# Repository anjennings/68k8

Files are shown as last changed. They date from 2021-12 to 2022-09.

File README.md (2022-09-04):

# 68k8

## Specs
+ 68008 CPU
+ 68681 UART
+ 32K EEPROM
+ 2 x 512k SRAM Sockets 
	+ 2nd chip (lower) optional
+ Serial EEPROM 
	+ Remotely Programable
	+ Sizes Vary but 64k-128k Recommended
+ Micro SD Card
	+ I haven't even begun to test this so idk

## TODO List 1/7/21 (preferably in this order)
+ Arduino code for programming SROM
+ Wait for new 68681 chips to arrive
+ Finish UART A drivers
+ Finish Timer drivers
+ Test/Finish SROM Drivers
+ Order higher capacity SROM
+ Order sd card slot
+ Order 32-DIP socket for 2nd RAM slot
+ Write bootloader that boots from SROM
+ Solder SD card
+ Solder 2nd RAM socket
+ Assign traps to UART/SPI functions
+ Fuzix Branch

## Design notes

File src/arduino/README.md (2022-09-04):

# Arduino
Arduino projects used for testing and troubleshooting hardware issues

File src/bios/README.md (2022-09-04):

# 68k8 BIOS

Boots from 32k EEPROM, inits UART, and loads from Serial EEPROM if present

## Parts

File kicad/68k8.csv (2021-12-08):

Reference | Value | Footprint | Datasheet
U2 | L7805 | Package_TO_SOT_THT:TO-220-3_Vertical | http://www.st.com/content/ccc/resource/technical/document/datasheet/41/4f/b3/b0/12/d4/47/88/CD00000444.pdf/files/CD00000444.pdf/jcr:content/translations/en.CD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
U1 | LF33_TO220 | Package_TO_SOT_THT:TO-220-3_Horizontal_TabDown | http://www.st.com/content/ccc/resource/technical/document/datasheet/c4/0e/7e/2a/be/bc/4c/bd/CD00000546.pdf/files/CD00000546.pdf/jcr:content/translations/en.CD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
C1 | .1uF | Capacitor_THT:CP_Radial_D8.0mm_P2.50mm | ~
C2 | .33uF | Capacitor_THT:CP_Radial_D8.0mm_P2.50mm | ~
C3 | 2.2uF | Capacitor_THT:CP_Radial_D8.0mm_P2.50mm | ~
C4 | .1uF | Capacitor_THT:CP_Radial_D8.0mm_P2.50mm | ~
H0 | MountingHole | MountingHole:MountingHole_4mm | ~
H1 | MountingHole | MountingHole:MountingHole_4mm | ~
H2 | MountingHole | MountingHole:MountingHole_4mm | ~
H3 | MountingHole | MountingHole:MountingHole_4mm | ~
J00 | Barrel_Jack_Switch | Connector_BarrelJack:BarrelJack_Horizontal | ~
D0 | POW_LED | LED_THT:LED_D3.0mm | ~
R0 | 2K | Resistor_THT:R_Axial_DIN0309_L9.0mm_D3.2mm_P2.54mm_Vertical | ~
D1 | 1N4001 | Diode_THT:D_DO-41_SOD81_P10.16mm_Horizontal | ~
U400 | GAL16V8 | Package_DIP:DIP-20_W7.62mm_LongPads
C400 | 22pF | Capacitor_THT:C_Rect_L4.0mm_W2.5mm_P2.50mm | ~
U300 | 68681 | Package_DIP:DIP-40_W15.24mm_LongPads
U301 | MCP2221AxP | Package_DIP:DIP-14_W7.62mm_LongPads | http://ww1.microchip.com/downloads/en/DeviceDoc/20005565B.pdf
Y300 | 3.6864 MHz | Crystal:Crystal_HC18-U_Vertical | ~
22pF2 | CX2 | Capacitor_THT:C_Rect_L4.0mm_W2.5mm_P2.50mm | ~
22pF1 | CX1 | Capacitor_THT:C_Rect_L4.0mm_W2.5mm_P2.50mm | ~
J300 | Conn_01x02_Male | Connector_PinSocket_2.54mm:PinSocket_1x02_P2.54mm_Vertical | ~
C7 | 22pF | Capacitor_THT:C_Rect_L4.0mm_W2.5mm_P2.50mm | ~
J302 | USB_B | Connector_USB:USB_B_OST_USB-B1HSxx_Horizontal | ~
J301 | Conn_01x03_Male | Connector_PinSocket_2.54mm:PinSocket_1x03_P2.54mm_Vertical | ~
RN300 | 10K | Resistor_THT:R_Array_SIP5 | http://www.vishay.com/docs/31509/csc.pdf
J303 | Conn_01x07 | Connector_PinHeader_2.54mm:PinHeader_1x07_P2.54mm_Vertical | ~
C300 | 22pF | Capacitor_THT:C_Rect_L4.0mm_W2.5mm_P2.50mm | ~
C301 | 22pF | Capacitor_THT:C_Rect_L4.0mm_W2.5mm_P2.50mm | ~
RN301 | 2K | Resistor_THT:R_Array_SIP5 | http://www.vishay.com/docs/31509/csc.pdf
D300 | LED | LED_THT:LED_D3.0mm | ~
D301 | LED | LED_THT:LED_D3.0mm | ~
U330 | 25LCxxx | Package_DIP:DIP-8_W7.62mm | http://ww1.microchip.com/downloads/en/DeviceDoc/21832H.pdf
J330 | Conn_02x04_Top_Bottom | Connector_PinHeader_2.54mm:PinHeader_2x04_P2.54mm_Vertical | ~
U331 | 74LS126 | Package_DIP:DIP-14_W7.62mm | http://www.ti.com/lit/gpn/sn74LS126
C331 | 22pF | Capacitor_THT:C_Rect_L4.0mm_W2.5mm_P2.50mm | ~
C330 | 22pF | Capacitor_THT:C_Rect_L4.0mm_W2.5mm_P2.50mm | ~
U101 | 74LS07 | Package_DIP:DIP-14_W7.62mm | www.ti.com/lit/ds/symlink/sn74ls07.pdf
J320 | Micro_SD_Card_Det | Connector_Card:microSD_HC_Molex_104031-0811 | https://www.hirose.com/product/en/download_file/key_name/DM3/category/Catalog/doc_file_id/49662/?item_id=195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
RN320 | 10k | Resistor_THT:R_Array_SIP6 | http://www.vishay.com/docs/31509/csc.pdf
U100 | 68008D | Package_DIP:DIP-48_W15.24mm_LongPads | https://www.nxp.com/docs/en/reference-manual/MC68000UM.pdf
RN1 | R_Network10 | Resistor_THT:R_Array_SIP11 | http://www.vishay.com/docs/31509/csc.pdf
U102 | GAL16V8 | Package_DIP:DIP-20_W7.62mm_LongPads
CLK1 | 10.000 MHz | Oscillator:Oscillator_DIP-14 | http://cdn-reichelt.de/documents/datenblatt/B400/OSZI.pdf
C100 | 22pF | Capacitor_THT:C_Rect_L4.0mm_W2.5mm_P2.50mm | ~
C101 | 22pF | Capacitor_THT:C_Rect_L4.0mm_W2.5mm_P2.50mm | ~
C102 | 22pF | Capacitor_THT:C_Rect_L4.0mm_W2.5mm_P2.50mm | ~
C103 | 22pF | Capacitor_THT:C_Rect_L4.0mm_W2.5mm_P2.50mm | ~
U110 | LM555 | Package_DIP:DIP-8_W7.62mm_LongPads | http://www.ti.com/lit/ds/symlink/lm555.pdf
SW110 | SW_Push | Button_Switch_THT:SW_PUSH_6mm_H8.5mm | ~
C111 | 10nF | Capacitor_THT:C_Rect_L4.0mm_W2.5mm_P2.50mm | ~
 | 10uF | Capacitor_THT:C_Rect_L4.0mm_W2.5mm_P2.50mm | ~
C110 | 22pF | Capacitor_THT:C_Rect_L4.0mm_W2.5mm_P2.50mm | ~
C113 | 100nF | Capacitor_THT:C_Rect_L4.0mm_W2.5mm_P2.50mm | ~
U200 | AS6C4008-55PCN | Package_DIP:DIP-32_W15.24mm_LongPads | https://www.alliancememory.com/wp-content/uploads/pdf/AS6C4008.pdf
U202 | 28C256 | Package_DIP:DIP-28_W15.24mm_LongPads | http://ww1.microchip.com/downloads/en/DeviceDoc/doc0006.pdf
C200 | 22pF | Capacitor_THT:C_Rect_L4.0mm_W2.5mm_P2.50mm | ~
C201 | 22pF | Capacitor_THT:C_Rect_L4.0mm_W2.5mm_P2.50mm | ~
C202 | 22pF | Capacitor_THT:C_Rect_L4.0mm_W2.5mm_P2.50mm | ~
U201 | AS6C4008-55PCN | Package_DIP:DIP-32_W15.24mm_LongPads | https://www.alliancememory.com/wp-content/uploads/pdf/AS6C4008.pdf

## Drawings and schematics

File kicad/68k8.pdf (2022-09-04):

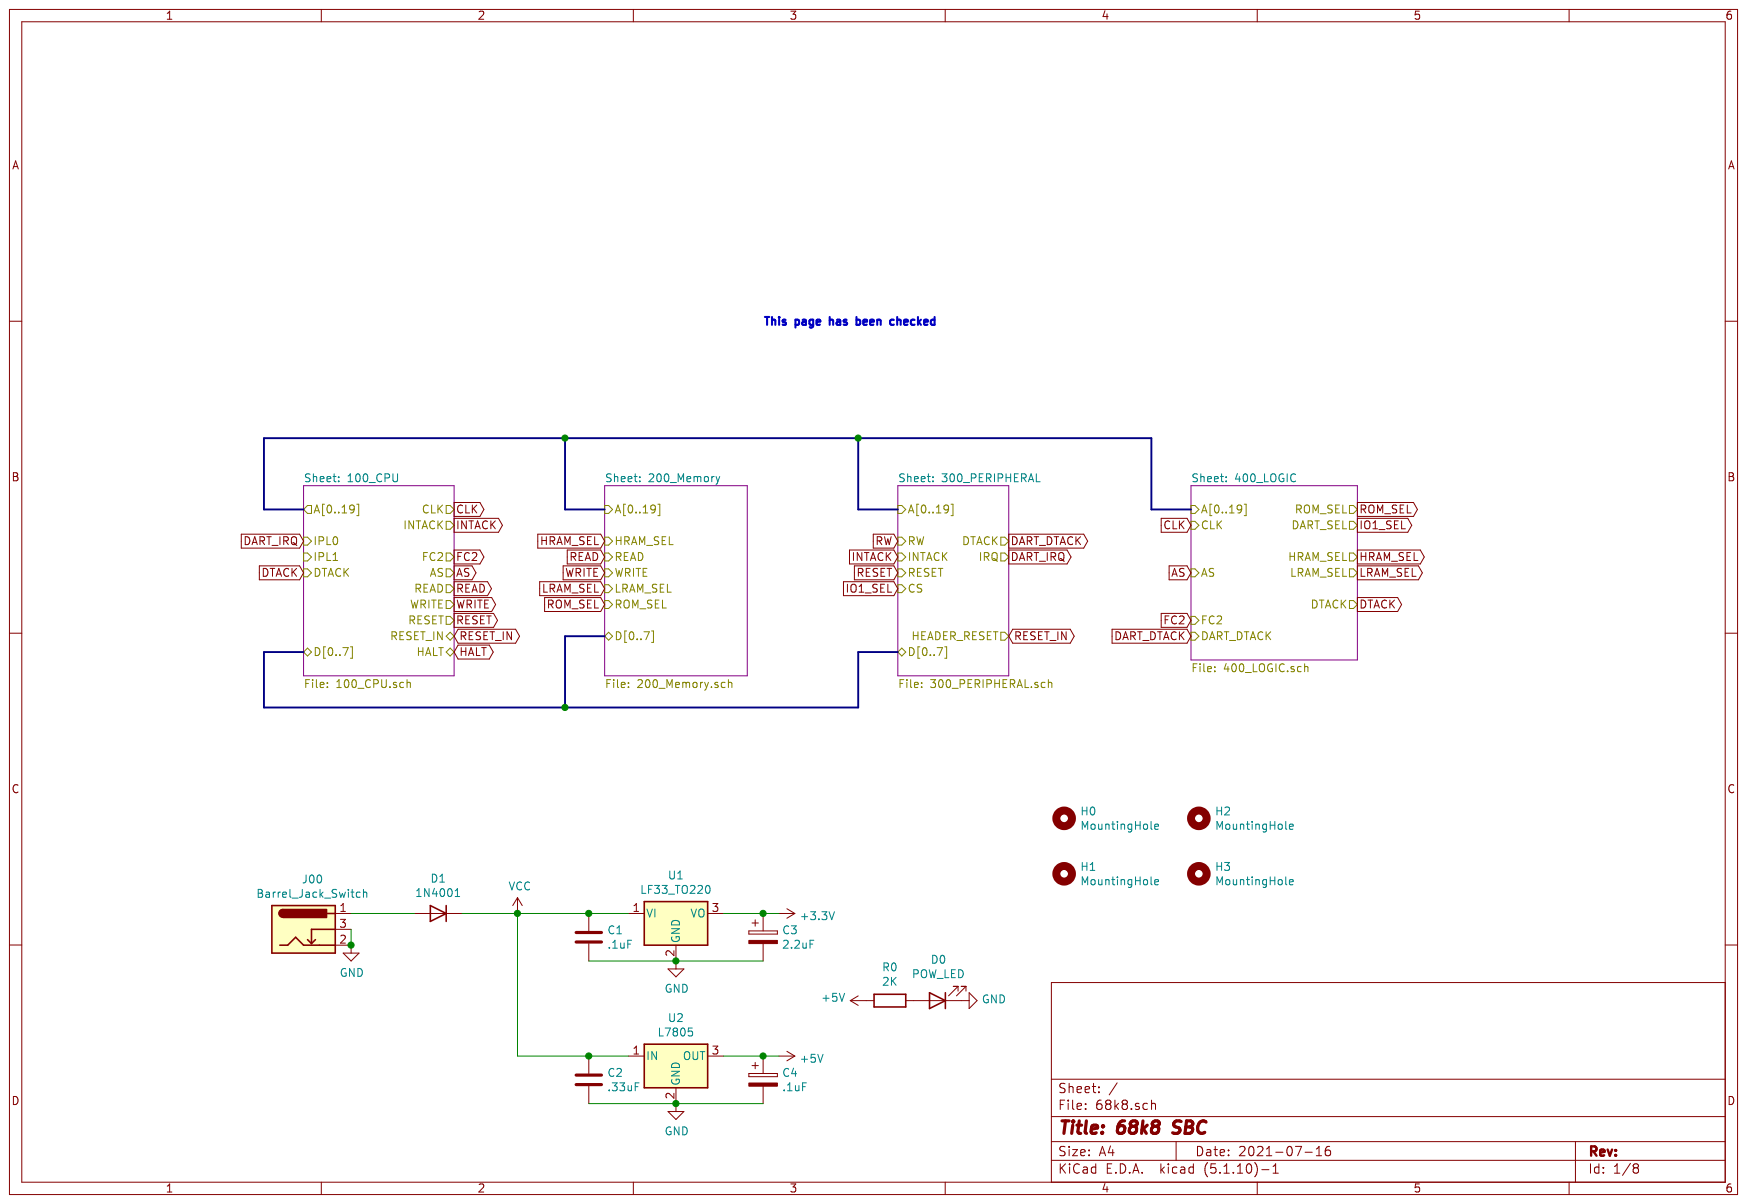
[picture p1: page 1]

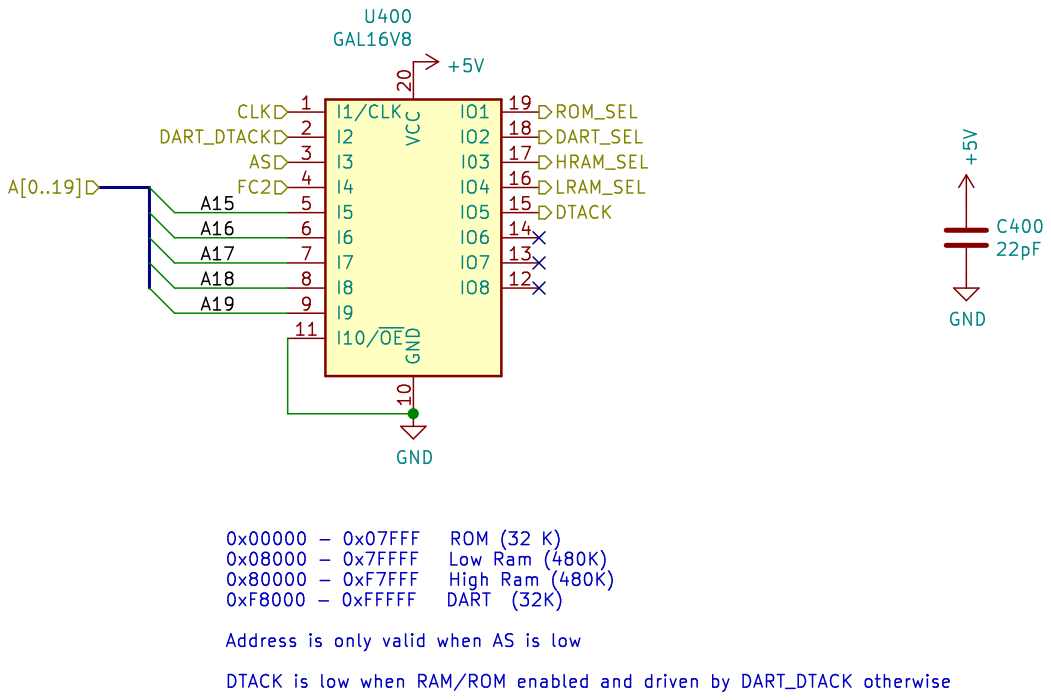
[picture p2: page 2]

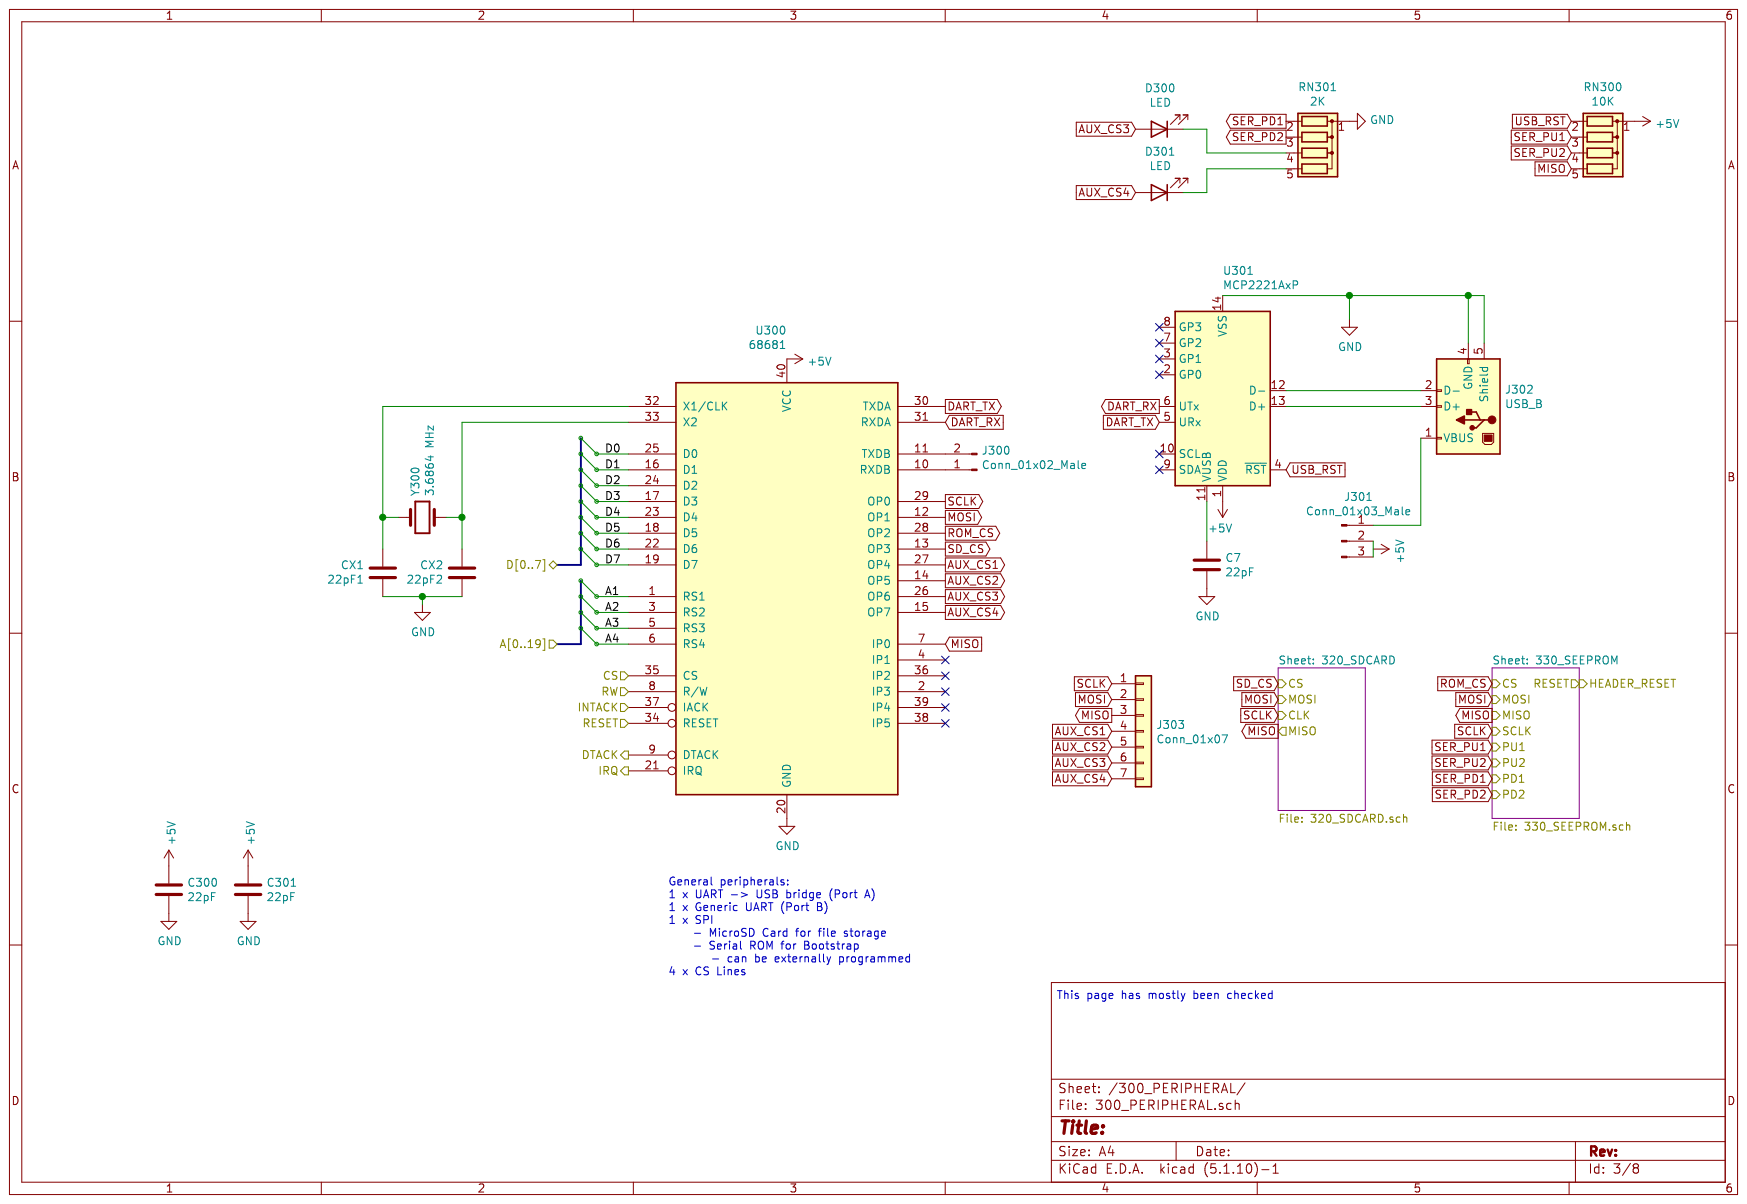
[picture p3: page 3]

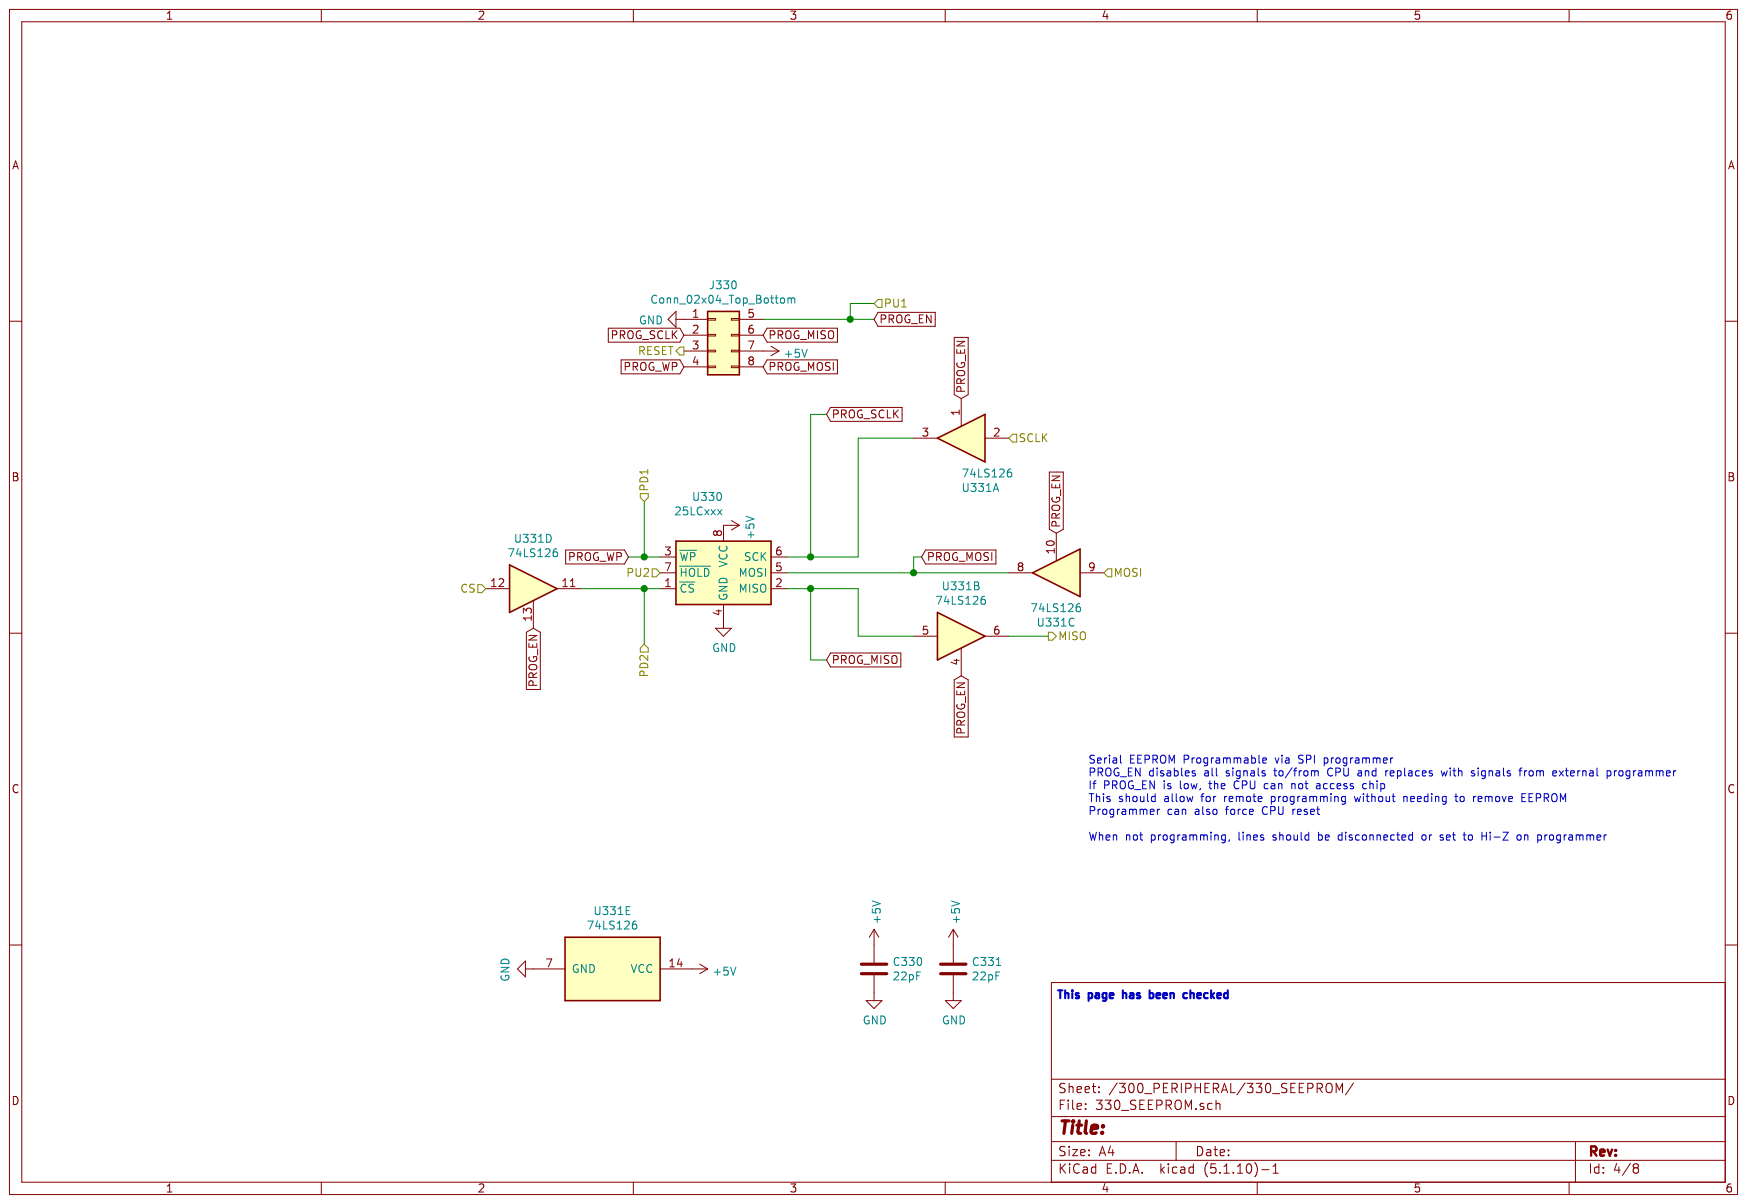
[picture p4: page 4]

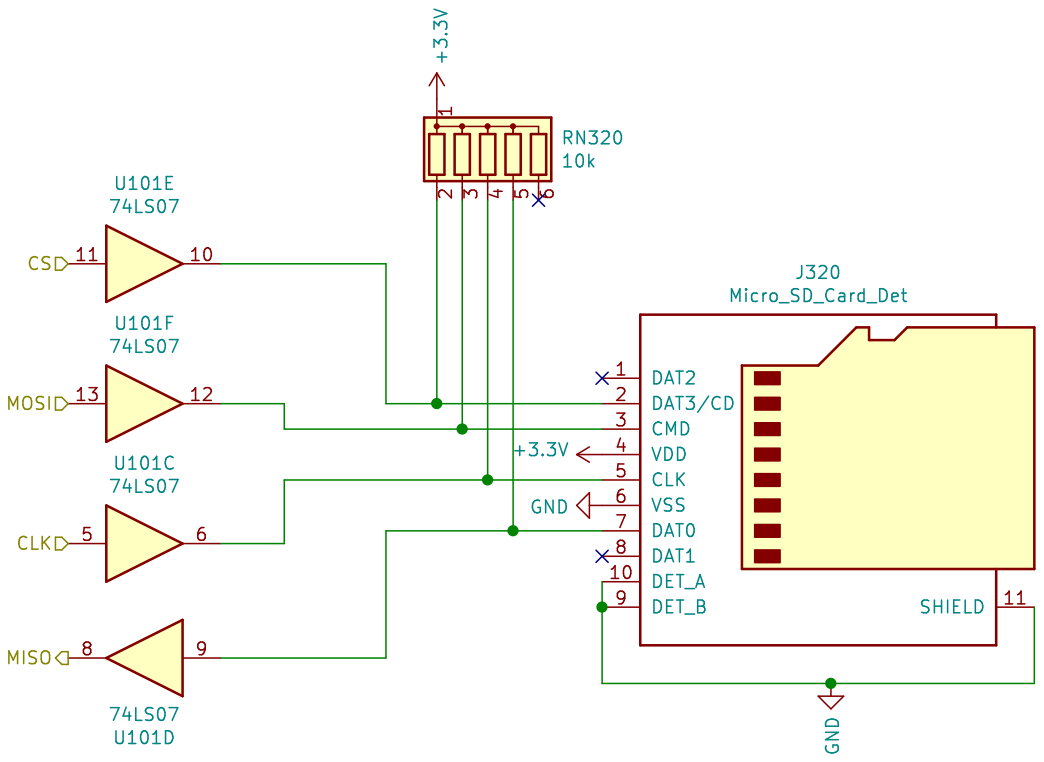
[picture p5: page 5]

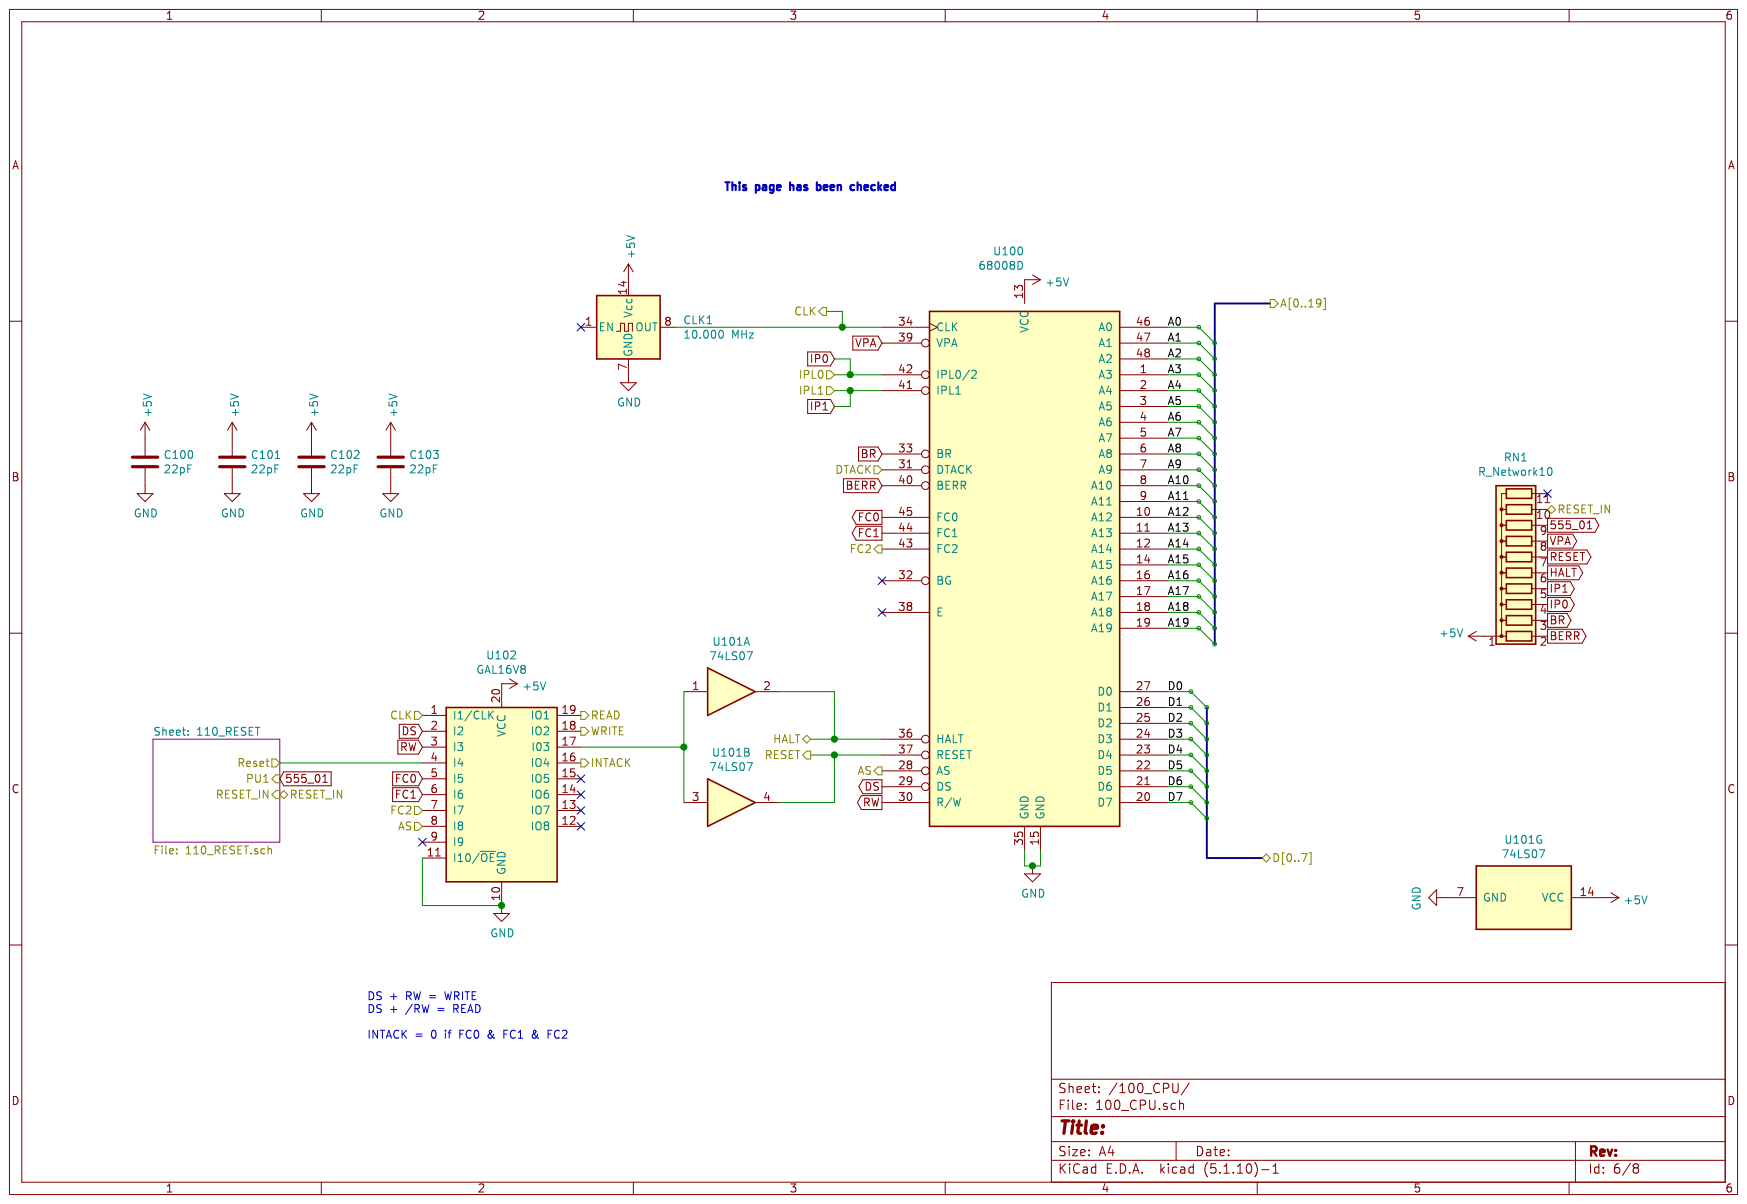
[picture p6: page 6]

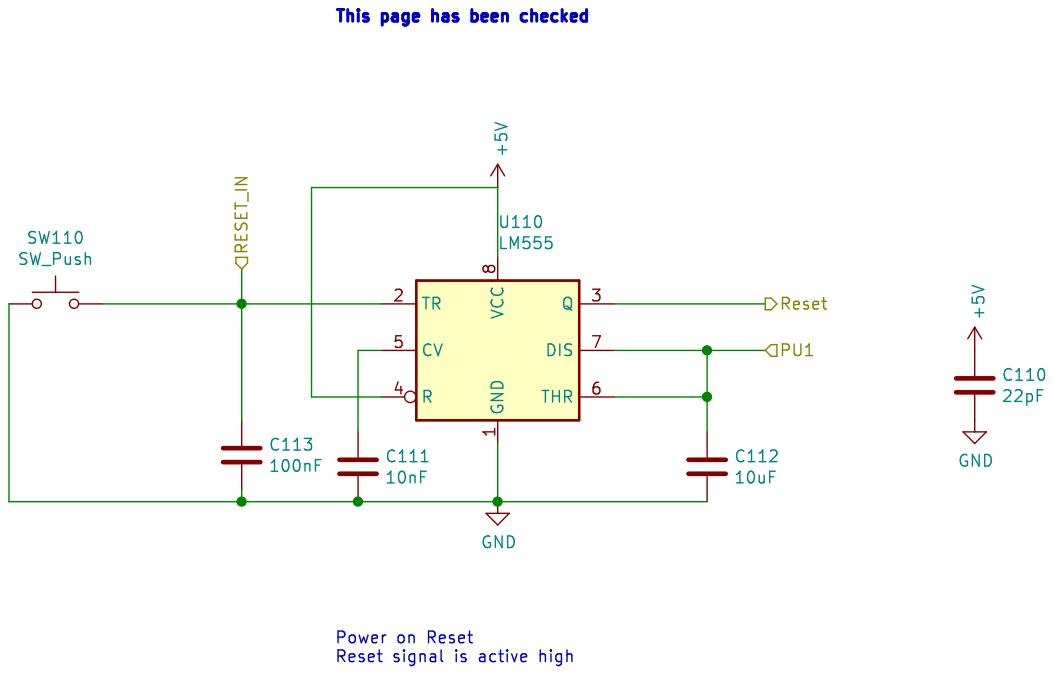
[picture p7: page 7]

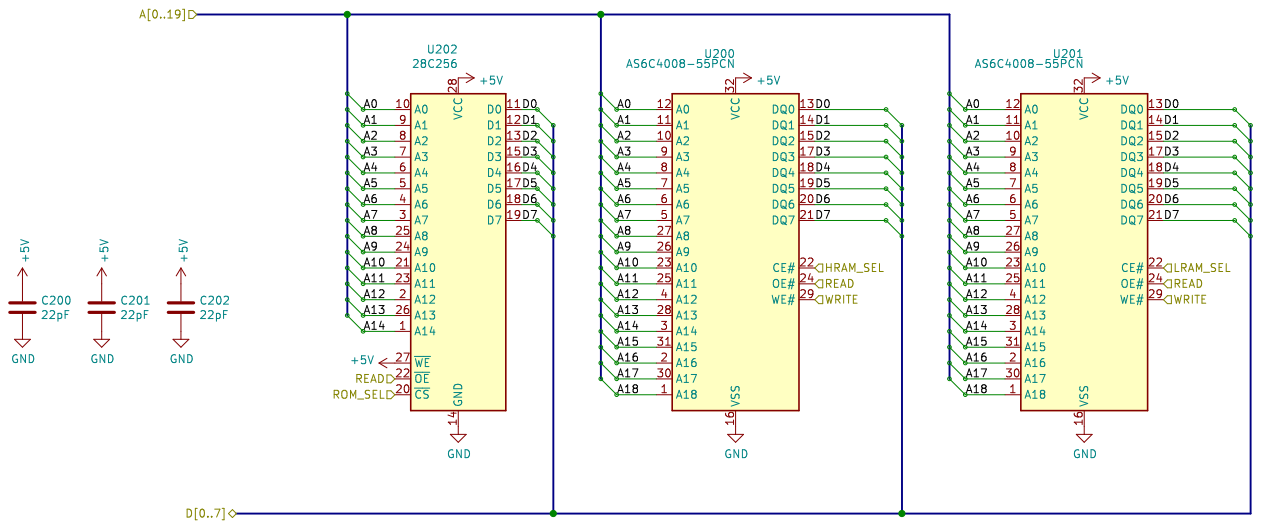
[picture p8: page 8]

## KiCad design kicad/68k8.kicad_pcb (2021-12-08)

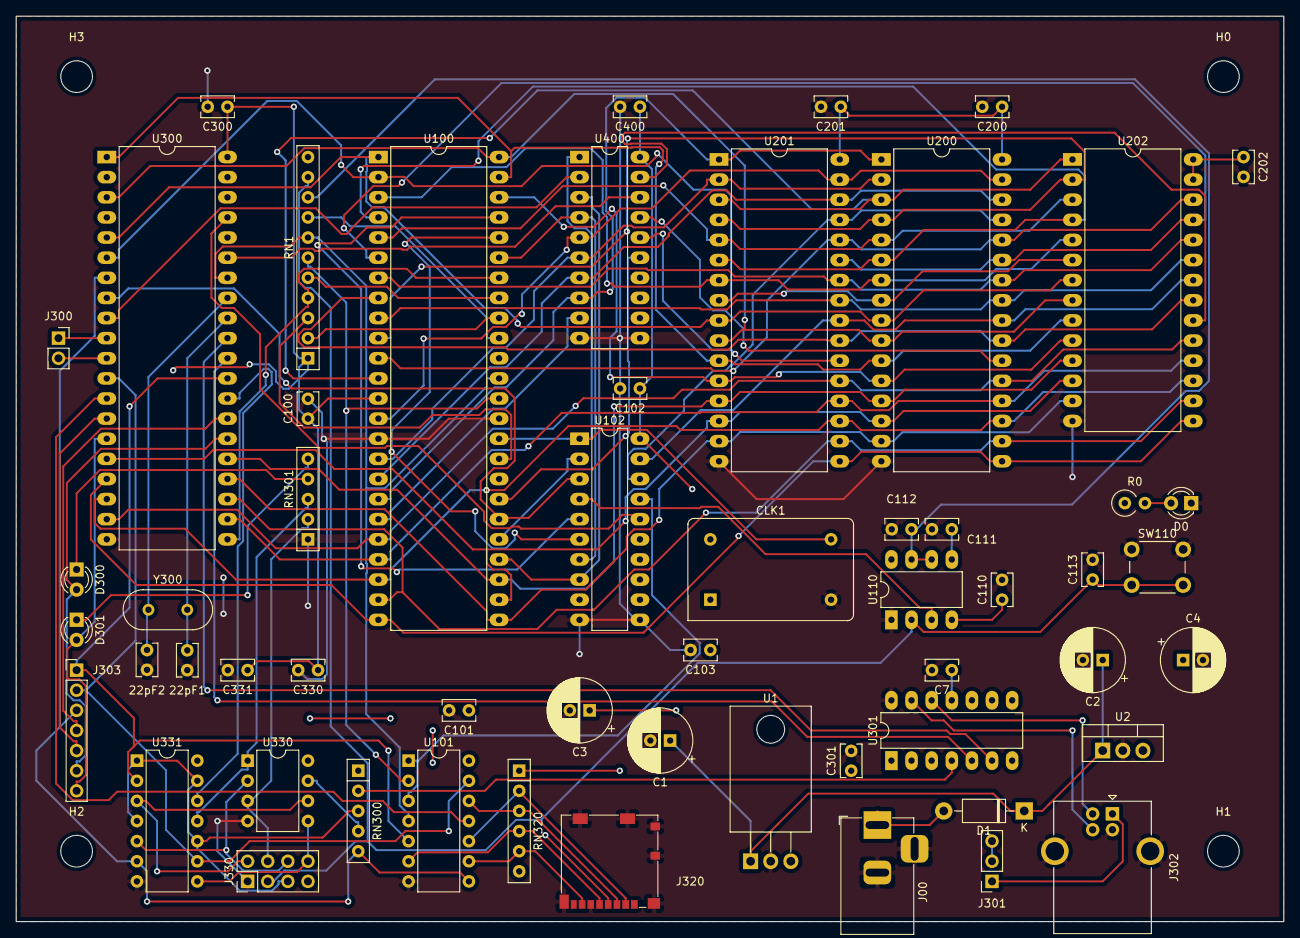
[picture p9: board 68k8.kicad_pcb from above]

Board: 2 copper layers, 160.0 x 114.3 mm, 60 parts (0 on the bottom side), 96 nets.

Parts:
22pF1: CX1; C_Rect_L4.0mm_W2.5mm_P2.50mm
22pF2: CX2; C_Rect_L4.0mm_W2.5mm_P2.50mm
C1, C4: .1uF; CP_Radial_D8.0mm_P2.50mm
C2: .33uF; CP_Radial_D8.0mm_P2.50mm
C3: 2.2uF; CP_Radial_D8.0mm_P2.50mm
C7, C100, C101, C102, C103, C110, C200, C201, C202, C300, C301, C330, C331, C400: 22pF; C_Rect_L4.0mm_W2.5mm_P2.50mm
C111: 10nF; C_Rect_L4.0mm_W2.5mm_P2.50mm
C112: 10uF; C_Rect_L4.0mm_W2.5mm_P2.50mm
C113: 100nF; C_Rect_L4.0mm_W2.5mm_P2.50mm
CLK1: 10.000 MHz; Oscillator_DIP-14
D0: POW_LED; LED_D3.0mm
D1: 1N4001; D_DO-41_SOD81_P10.16mm_Horizontal
D300, D301: LED; LED_D3.0mm
H0, H1, H2, H3: MountingHole; MountingHole_4mm
J00: Barrel_Jack_Switch; BarrelJack_Horizontal
J300: Conn_01x02_Male; PinSocket_1x02_P2.54mm_Vertical
J301: Conn_01x03_Male; PinSocket_1x03_P2.54mm_Vertical
J302: USB_B; USB_B_OST_USB-B1HSxx_Horizontal
J303: Conn_01x07; PinHeader_1x07_P2.54mm_Vertical
J320: Micro_SD_Card_Det; microSD_HC_Molex_104031-0811
J330: Conn_02x04_Top_Bottom; PinHeader_2x04_P2.54mm_Vertical
R0: 2K; R_Axial_DIN0309_L9.0mm_D3.2mm_P2.54mm_Vertical
RN1: R_Network10; R_Array_SIP11
RN300: 10K; R_Array_SIP5
RN301: 2K; R_Array_SIP5
RN320: 10k; R_Array_SIP6
SW110: SW_Push; SW_PUSH_6mm_H8.5mm
U1: LF33_TO220; TO-220-3_Horizontal_TabDown
U2: L7805; TO-220-3_Vertical
U100: 68008D; DIP-48_W15.24mm_LongPads
U101: 74LS07; DIP-14_W7.62mm
U102, U400: GAL16V8; DIP-20_W7.62mm_LongPads
U110: LM555; DIP-8_W7.62mm_LongPads
U200, U201: AS6C4008-55PCN; DIP-32_W15.24mm_LongPads
U202: 28C256; DIP-28_W15.24mm_LongPads
U300: 68681; DIP-40_W15.24mm_LongPads
U301: MCP2221AxP; DIP-14_W7.62mm_LongPads
U330: 25LCxxx; DIP-8_W7.62mm
U331: 74LS126; DIP-14_W7.62mm
Y300: 3.6864 MHz; Crystal_HC18-U_Vertical

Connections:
555_01: C112.1, RN1.9, U110.6, U110.7
+3V3: C3.1, J320.4, RN320.1, U1.3
+5V: C4.1, C100.1, C101.1, C102.1, C103.1, C110.1, C200.1, C201.1, C202.1, C300.1, C301.1, C330.1, C331.1, C400.1, CLK1.14, J330.7, R0.1, RN1.1, RN300.1, U2.3, U100.13, U101.14, U102.20, U110.4, U110.8, U200.32, U201.32, U202.27, U202.28, U300.40, U301.1, U330.8, U331.14, U400.20
/100_CPU/110_RESET/Reset: U102.4, U110.3
/100_CPU/A0: U100.46, U200.12, U201.12, U202.10
/100_CPU/A1: U100.47, U200.11, U201.11, U202.9, U300.1
/100_CPU/A2: U100.48, U200.10, U201.10, U202.8, U300.3
/100_CPU/A3: U100.1, U200.9, U201.9, U202.7, U300.5
/100_CPU/A4: U100.2, U200.8, U201.8, U202.6, U300.6
/100_CPU/A5: U100.3, U200.7, U201.7, U202.5
/100_CPU/A6: U100.4, U200.6, U201.6, U202.4
/100_CPU/A7: U100.5, U200.5, U201.5, U202.3
/100_CPU/A8: U100.6, U200.27, U201.27, U202.25
/100_CPU/A9: U100.7, U200.26, U201.26, U202.24
/100_CPU/A10: U100.8, U200.23, U201.23, U202.21
/100_CPU/A11: U100.9, U200.25, U201.25, U202.23
/100_CPU/A12: U100.10, U200.4, U201.4, U202.2
/100_CPU/A13: U100.11, U200.28, U201.28, U202.26
/100_CPU/A14: U100.12, U200.3, U201.3, U202.1
/100_CPU/A15: U100.14, U200.31, U201.31, U400.5
/100_CPU/A16: U100.16, U200.2, U201.2, U400.6
/100_CPU/A17: U100.17, U200.30, U201.30, U400.7
/100_CPU/A18: U100.18, U200.1, U201.1, U400.8
/100_CPU/A19: U100.19, U400.9
/100_CPU/D0: U100.27, U200.13, U201.13, U202.11, U300.25
/100_CPU/D1: U100.26, U200.14, U201.14, U202.12, U300.16
/100_CPU/D2: U100.25, U200.15, U201.15, U202.13, U300.24
/100_CPU/D3: U100.24, U200.17, U201.17, U202.15, U300.17
/100_CPU/D4: U100.23, U200.18, U201.18, U202.16, U300.23
/100_CPU/D5: U100.22, U200.19, U201.19, U202.17, U300.18
/100_CPU/D6: U100.21, U200.20, U201.20, U202.18, U300.22
/100_CPU/D7: U100.20, U200.21, U201.21, U202.19, U300.19
AS: U100.28, U102.8, U400.3
AUX_CS1: J303.4, U300.27
AUX_CS2: J303.5, U300.14
AUX_CS3: D300.2, J303.6, U300.26
AUX_CS4: D301.2, J303.7, U300.15
BERR: RN1.2, U100.40
BR: RN1.3, U100.33
CLK: CLK1.8, U100.34, U102.1, U400.1
DART_DTACK: U300.9, U400.2
DART_IRQ: RN1.4, U100.42, U300.21
DART_RX: U300.31, U301.6
DART_TX: U300.30, U301.5
DS: U100.29, U102.2
DTACK: U100.31, U400.15
FC0: U100.45, U102.5
FC1: U100.44, U102.6
FC2: U100.43, U102.7, U400.4
GND: 22pF1.1, 22pF2.1, C1.2, C2.2, C3.2, C4.2, C7.2, C100.2, C101.2, C102.2, C103.2, C110.2, C111.2, C112.2, C113.2, C200.2, C201.2, C202.2, C300.2, C301.2, C330.2, C331.2, C400.2, CLK1.7, D0.1, J00.2, J00.3, J302.4, J302.5, J320.6, J320.9, J320.10, J320.11, J330.1, RN301.1, SW110.1, U1.2, U2.2, U100.15, U100.35, U101.7, U102.10, U102.11, U110.1, U200.16, U201.16, U202.14, U300.20, U301.14, U330.4, U331.7, U400.10, U400.11
HALT: RN1.6, U100.36, U101.2
HRAM_SEL: U200.22, U400.17
INTACK: U102.16, U300.37
IO1_SEL: U300.35, U400.18
IP1: RN1.5, U100.41
LRAM_SEL: U201.22, U400.16
MISO: J303.3, RN300.5, U101.8, U300.7, U331.6
MOSI: J303.2, U101.13, U300.12, U331.9
unnamed: 22pF1.2, U300.32, Y300.1
unnamed: 22pF2.2, U300.33, Y300.2
unnamed: C7.1, U301.11
unnamed: C111.1, U110.5
unnamed: D0.2, R0.2
unnamed: D1.2, J00.1
unnamed: D300.1, RN301.4
unnamed: D301.1, RN301.5
unnamed: J300.1, U300.10
unnamed: J300.2, U300.11
unnamed: J301.1, J302.1
unnamed: J301.2, J301.3
unnamed: J302.2, U301.12
unnamed: J302.3, U301.13
unnamed: J320.2, RN320.2, U101.10
unnamed: J320.3, RN320.3, U101.12
unnamed: J320.5, RN320.4, U101.6
unnamed: J320.7, RN320.5, U101.9
unnamed: U101.1, U101.3, U102.17
PROG_EN: J330.5, RN300.3, U331.1, U331.4, U331.10, U331.13
PROG_MISO: J330.6, U330.2, U331.5
PROG_MOSI: J330.8, U330.5, U331.8
PROG_SCLK: J330.2, U330.6, U331.3
PROG_WP: J330.4, RN301.2, U330.3
READ: U102.19, U200.24, U201.24, U202.22
RESET: RN1.7, U100.37, U101.4, U300.34
RESET_IN: C113.1, J330.3, RN1.10, SW110.2, U110.2
ROM_CS: U300.28, U331.12
ROM_SEL: U202.20, U400.19
RW: U100.30, U102.3, U300.8
SCLK: J303.1, U101.5, U300.29, U331.2
SD_CS: U101.11, U300.13
SER_PD2: RN301.3, U330.1, U331.11
SER_PU2: RN300.4, U330.7
USB_RST: RN300.2, U301.4
VCC: C1.1, C2.1, D1.1, U1.1, U2.1
VPA: RN1.8, U100.39
WRITE: U102.18, U200.29, U201.29

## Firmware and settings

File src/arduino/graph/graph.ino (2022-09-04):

int analogPin = A3; // potentiometer wiper (middle terminal) connected to analog pin 3
                    // outside leads to ground and +5V
int val = 0;  // variable to store the value read

void setup() {
  Serial.begin(9600);           //  setup serial
}

void loop() {
  val = analogRead(analogPin);  // read the input pin
  Serial.println(val);          // debug value
  delay(10);
}

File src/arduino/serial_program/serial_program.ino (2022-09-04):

// Remote programming of 25LCXXX Chip (up to 64k)

#include <SPI.h>

#define WP        9    // Write Protect
#define RESET     8    // CPU Reset

#define MAXSPEED  14000000
#define DATAORDER MSBFIRST
#define DATAMODE  SPI_MODE0   // Data in is rising edge, Data out is falling edge

#define BAUD      115200

void setup() {
  pinMode(WP, OUTPUT);
  digitalWrite(WP, HIGH);
  pinMode(RESET, OUTPUT);
  digitalWrite(RESET, HIGH);
  SPI.beginTransaction(SPISettings(MAXSPEED, DATAORDER, DATAMODE));
  SPI.begin();
  Serial.begin(BAUD);
}

void loop() {
  // put your main code here, to run repeatedly:
  
}

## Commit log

2021-10-11 updates from a long time ago
    [68k8.sch, Reset_Logic.sch, SDC.sch]
2021-10-11 Replaced most logic with EEPLD
    [68k.kicad_pcb, 68k.sch, 68k8.sch]
2021-11-30 Almost ready to route the PCB fully
    [100_CPU.sch, 110_RESET.sch, 200_Memory.sch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]
2021-11-30 removed rom/ram routes
    [68k8.kicad_pcb]
2021-12-01 moved larger footprints around a bit
    [68k8.kicad_pcb]
2021-12-02 ran autoroute
    [320_SDCARD.sch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]
2021-12-02 redid layout
    [330_SEEPROM.sch, 68k8.kicad_pcb]
2021-12-02 key routes placed
    [68k8.kicad_pcb]
2021-12-03 redid power routes
    [68k8.dsn, 68k8.kicad_pcb]
2021-12-04 almost done, almost
    [68k8-B_Cu.gbl, 68k8-B_Mask.gbs, 68k8-B_Paste.gbp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]
2021-12-05 gerbers have been sent
    [68k8-B_Cu.gbl, 68k8-B_Mask.gbs, 68k8-B_Paste.gbp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]
2021-12-08 Generated BOM
    [100_CPU.sch, 68k8.csv, 68k8.sch]
2021-12-08 Removed unused files
    [555_RESET.sch, 68k8 - Copy.sch, 68k8extra.dsn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]
2021-12-08 removed duplicates
    [68k8-B_Cu.gbl, 68k8-B_Mask.gbs, 68k8-B_Paste.gbp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]
2021-12-08 more unused files
    [68k8.dsn]
2021-12-08 Squashed commit of the following:
    commit 5bb93159fc2b2eccf3bc7271ff40b3cebe761d34
    Author: Aidan Jennings <anjennings@wisc.edu>
    Date: Wed Dec 8 17:37:30 2021 -0600
    commit 7e13d52fce64914ddbd187ffc850994f54d80316
    Author: Aidan Jennings <anjennings@wisc.edu>
    Date: Wed Dec 8 17:35:57 2021 -0600
    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
    [100_CPU.sch, 110_RESET.sch, 200_Memory.sch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]
2022-09-04 Old BIOS dev and GAL changes (#3)
    * starting on bios
    * added assembly makefile
    * switched asmbler to VASM
    * Began on DUART drivers
    * added more to bios
    * Exported schematics
    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
